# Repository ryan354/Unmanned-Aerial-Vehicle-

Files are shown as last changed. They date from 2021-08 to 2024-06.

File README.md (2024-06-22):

# Unmanned-Aerial-Vehicle-

Singapore Amazing Flying Machine Competition (SAFMC) is a Quadcopter or drone competition organized by DSO National Laboratories, Science Center Singapore and supported by the Ministry of Defense Singapore (MINDEF). In development of quadcopter many problems are found, such as collisions or crashes against obstacles and other quadcopter on the fly. This project discusses a PID control method for manipulating pitch and roll based on the proximity sensor as collision avoidance. The information obtained is then processed by PID control before entering the quadcopter flight controller. every quadcopter movement will be observed and evaluated to obtain stable movement. Use of wireless communication and telemetry data to facilitate the control of quadcopter with ground stations

okay let's dive into the project!!!!

1. UAV Design
<p align="center">
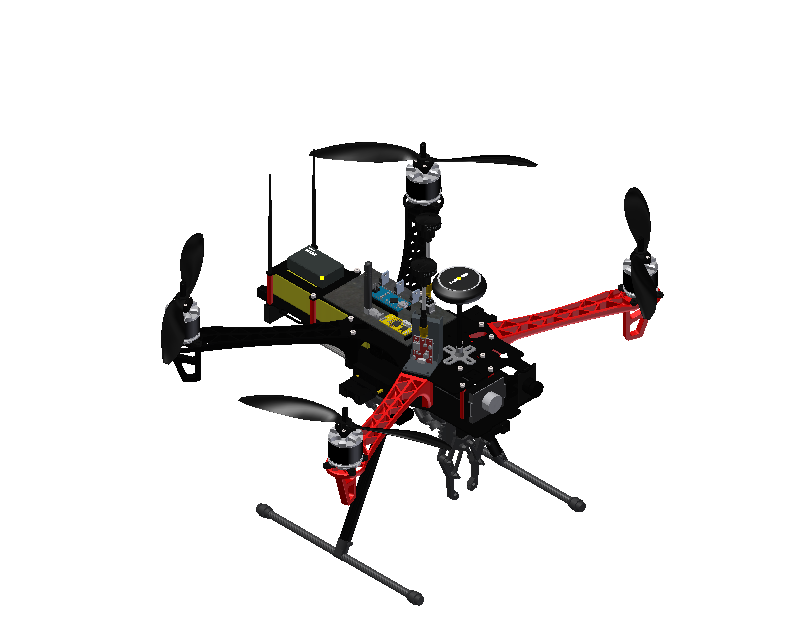
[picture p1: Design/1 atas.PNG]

</p>

<p align="center">
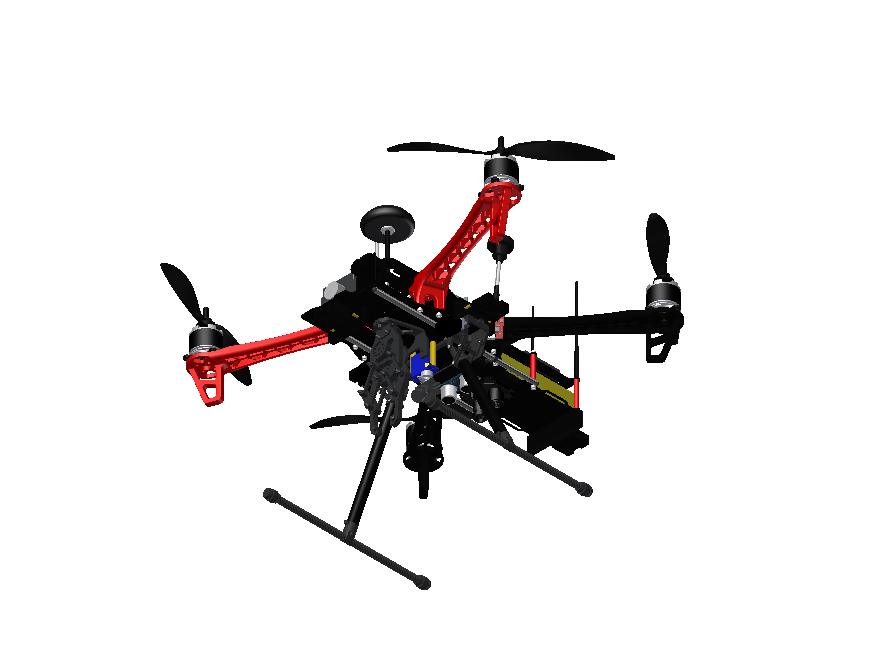
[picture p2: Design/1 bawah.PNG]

</p>

2. PCB (Printed Circuit Boards) Deisgn 
<p align="center">
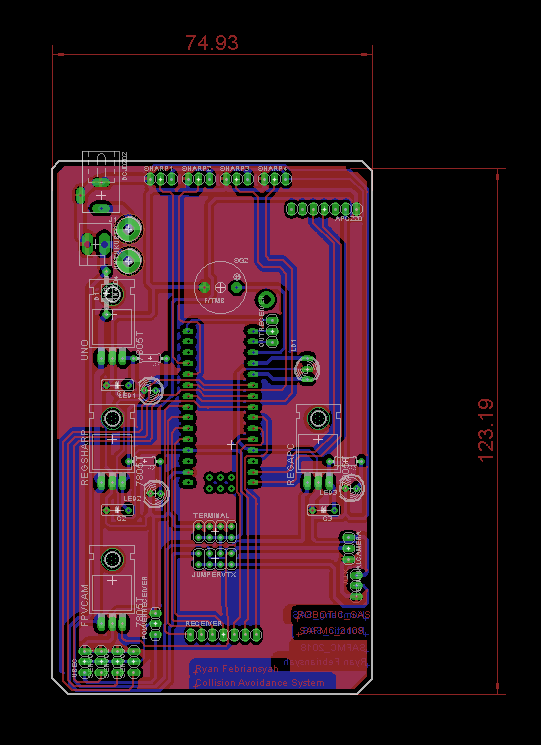
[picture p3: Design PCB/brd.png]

</p>

3. System Flowchart

<p align="center">
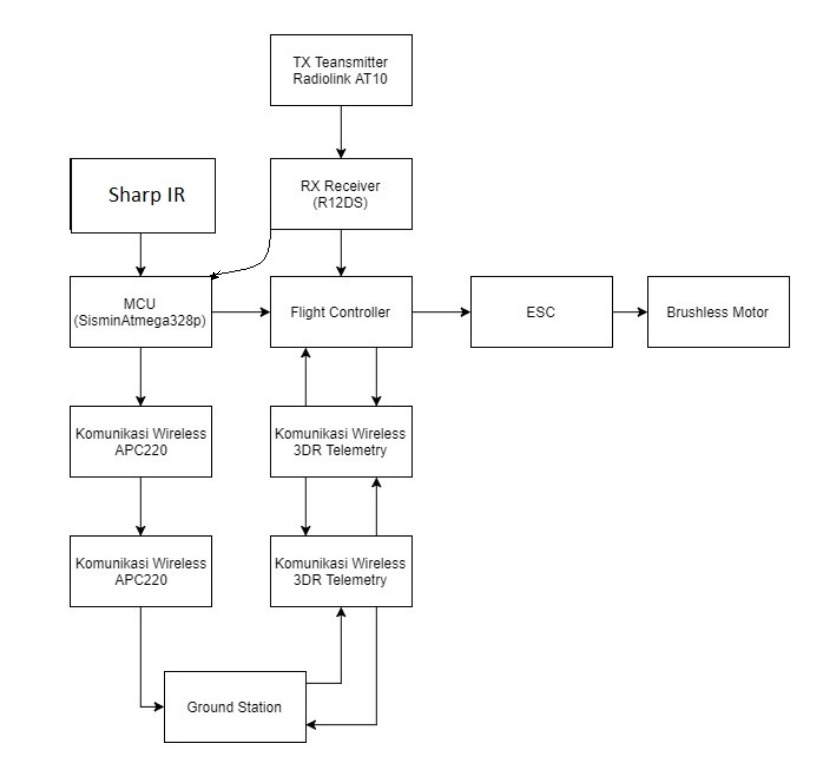
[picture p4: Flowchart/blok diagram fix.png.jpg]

</p>

Trial Video.
  
Unmanned-Aerial-Vehicle- (https://www.youtube.com/watch?v=qGmqiuEHwww)

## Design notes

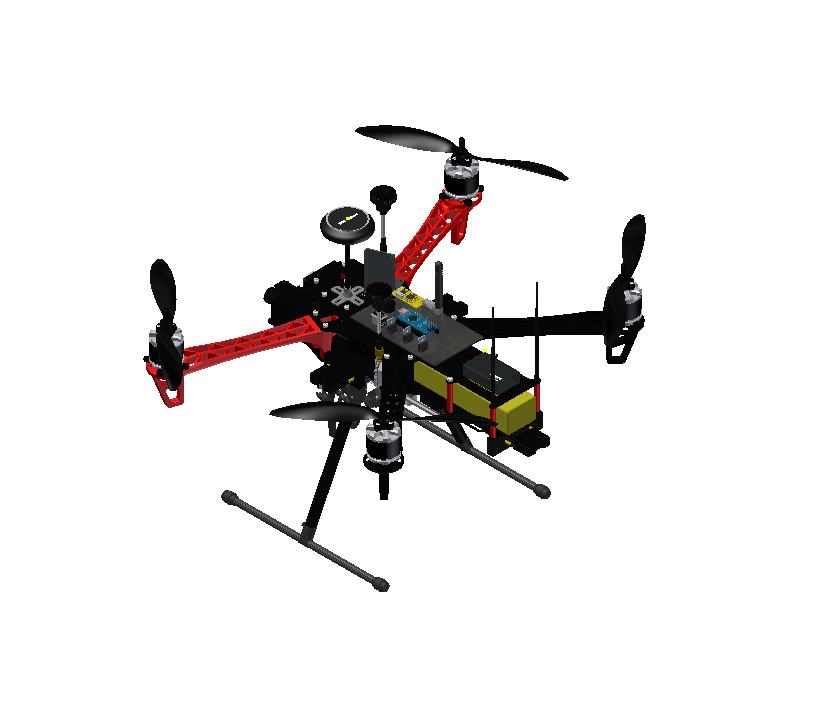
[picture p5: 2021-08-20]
Design/3 atas.PNG

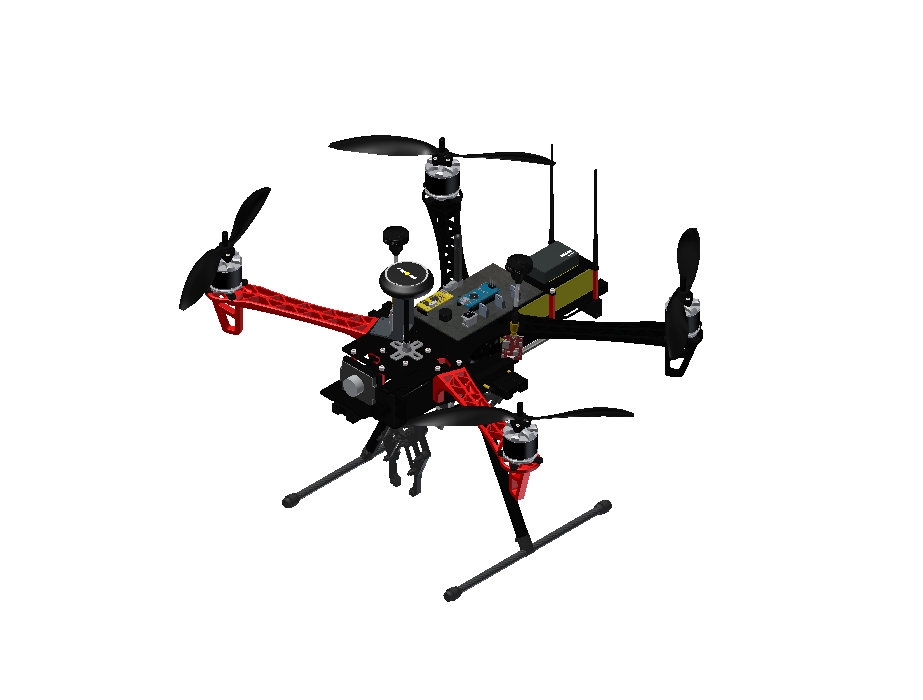
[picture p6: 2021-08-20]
Design/2 atas.PNG

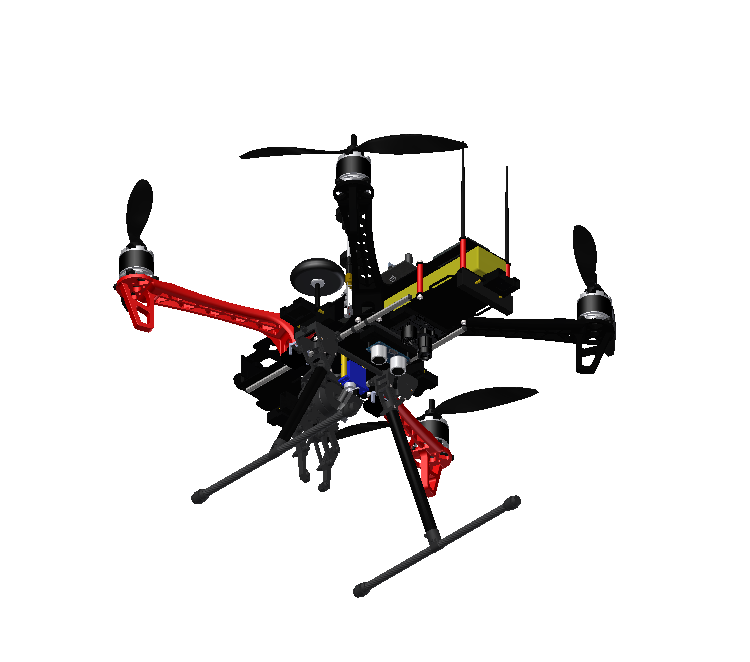
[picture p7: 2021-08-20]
Design/2 bawah.PNG

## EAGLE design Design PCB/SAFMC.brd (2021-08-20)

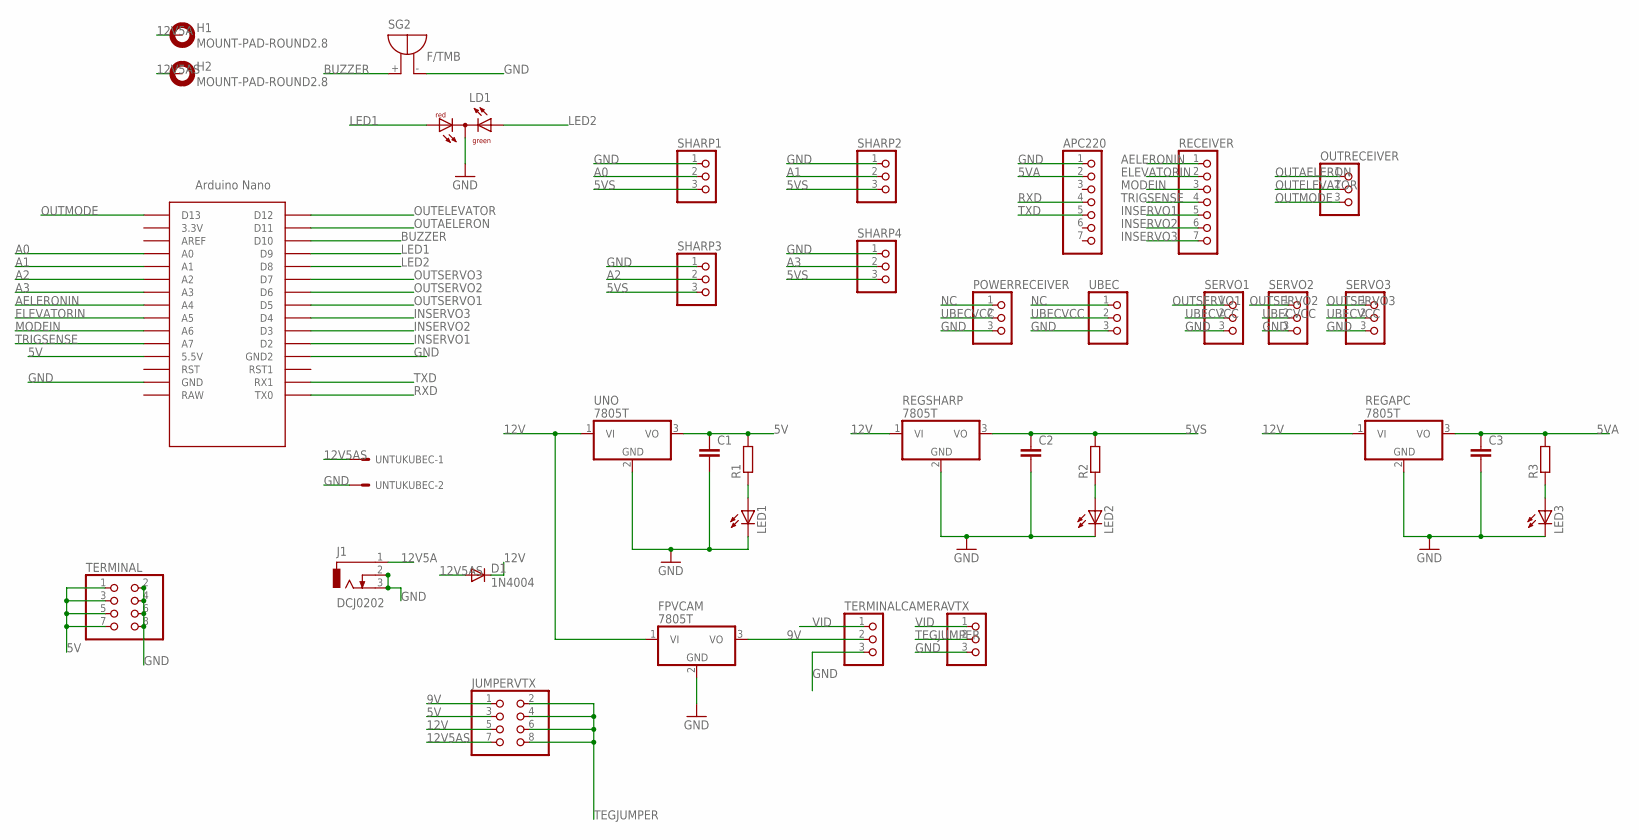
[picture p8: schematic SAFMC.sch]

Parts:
APC220: PINHD-1X7; 1X07
C1, C2, C3: C5/2.5; C5B2.5
D1: 1N4004; DO41-10
FPVCAM: 7805T; TO220H
H1, H2: MOUNT-PAD-ROUND2.8; 2,8-PAD
J1: DCJ0202
JUMPERVTX: PINHD-2X4; 2X04
LD1: DUOLED-RG-C; DUOLED-C-5MM
LED1, LED2, LED3: LED5MM
OUTRECEIVER: PINHD-1X3; 1X03
POWERRECEIVER: PINHD-1X3; 1X03
R1, R2, R3: R0204/7; 0204/7
RECEIVER: PINHD-1X7; 1X07
REGAPC: 7805T; TO220H
REGSHARP: 7805T; TO220H
SERVO1, SERVO2, SERVO3: PINHD-1X3; 1X03
SG2: F/TMB
SHARP1, SHARP2, SHARP3, SHARP4: PINHD-1X3; 1X03
TERMINAL: PINHD-2X4; 2X04
TERMINALCAMERA: PINHD-1X3; 1X03
U$2: NANO
UBEC: PINHD-1X3; 1X03
UNO: 7805T; TO220H
UNTUKUBEC: KK-156-2
VTX: PINHD-1X3; 1X03

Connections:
5V: C1.1, JUMPERVTX.3, R1.2, TERMINAL.1, TERMINAL.3, TERMINAL.5, TERMINAL.7, U$2.5V (5.5V), UNO.3 (VO)
5VA: APC220.2, C3.1, R3.2, REGAPC.3 (VO)
5VS: C2.1, R2.2, REGSHARP.3 (VO), SHARP1.3, SHARP2.3, SHARP3.3, SHARP4.3
9V: FPVCAM.3 (VO), JUMPERVTX.1, TERMINALCAMERA.2
12V: D1.C, FPVCAM.1 (VI), JUMPERVTX.5, REGAPC.1 (VI), REGSHARP.1 (VI), UNO.1 (VI)
12V5A: H1.B2,8, J1.1
12V5AS: D1.A, H2.B2,8, JUMPERVTX.7, UNTUKUBEC.1
A0: SHARP1.2, U$2.A0
A1: SHARP2.2, U$2.A1
A2: SHARP3.2, U$2.A2
A3: SHARP4.2, U$2.A3
AELERONIN: RECEIVER.1, U$2.A4
BUZZER: SG2.+, U$2.D10
ELEVATORIN: RECEIVER.2, U$2.A5
GND: APC220.1, C1.2, C2.2, C3.2, FPVCAM.2 (GND), J1.2, J1.3, LD1.C, LED1.K (C), LED2.K (C), LED3.K (C), POWERRECEIVER.3, REGAPC.2 (GND), REGSHARP.2 (GND), SERVO1.3, SERVO2.3, SERVO3.3, SG2.-, SHARP1.1, SHARP2.1, SHARP3.1, SHARP4.1, TERMINAL.2, TERMINAL.4, TERMINAL.6, TERMINAL.8, TERMINALCAMERA.3, U$2.GND, U$2.GND1 (GND2), UBEC.3, UNO.2 (GND), UNTUKUBEC.2, VTX.3
INSERVO1: RECEIVER.5, U$2.D2
INSERVO2: RECEIVER.6, U$2.D3
INSERVO3: RECEIVER.7, U$2.D4
LED1: LD1.AR, U$2.D9
LED2: LD1.AX (AG), U$2.D8
MODEIN: RECEIVER.3, U$2.A6
unnamed: LED3.A, R3.1
unnamed: LED1.A, R1.1
unnamed: LED2.A, R2.1
NC: POWERRECEIVER.1, UBEC.1
OUTAELERON: OUTRECEIVER.1, U$2.D11
OUTELEVATOR: OUTRECEIVER.2, U$2.D12
OUTMODE: OUTRECEIVER.3, U$2.D13
OUTSERVO1: SERVO1.1, U$2.D5
OUTSERVO2: SERVO2.1, U$2.D6
OUTSERVO3: SERVO3.1, U$2.D7
RXD: APC220.4, U$2.TX0
TEGJUMPER: JUMPERVTX.2, JUMPERVTX.4, JUMPERVTX.6, JUMPERVTX.8, VTX.2
TRIGSENSE: RECEIVER.4, U$2.A7
TXD: APC220.5, U$2.RX1
UBECVCC: POWERRECEIVER.2, SERVO1.2, SERVO2.2, SERVO3.2, UBEC.2
VID: TERMINALCAMERA.1, VTX.1

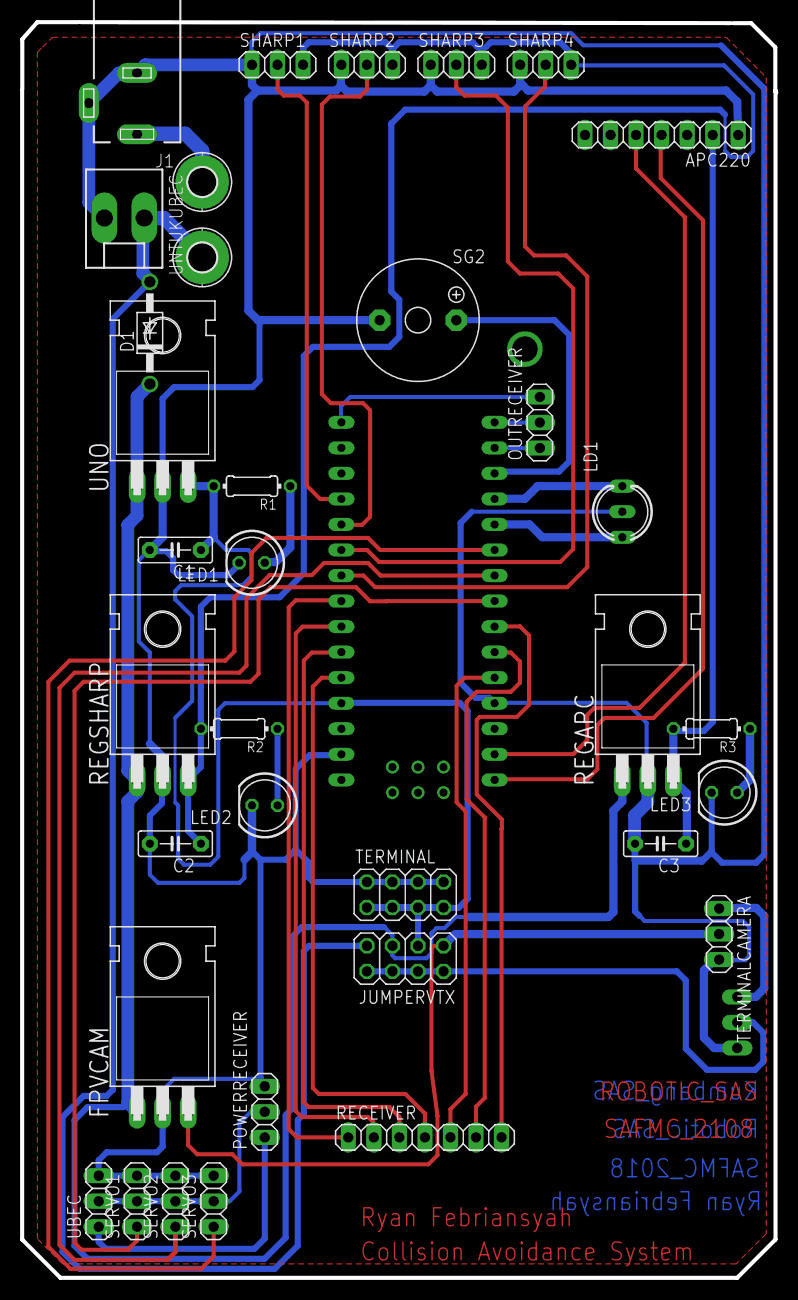
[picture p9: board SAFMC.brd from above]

Board: 2 copper layers, 75.0 x 124.9 mm, 37 parts (1 on the bottom side), 37 nets.

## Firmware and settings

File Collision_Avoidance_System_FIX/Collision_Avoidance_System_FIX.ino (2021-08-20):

#include <Servo.h>


//INPUT sensor sharp
int ir[4] = {A0, A1, A2, A3};
//INPUT Receiver
#define aeleronIN  A4
#define elevatorIN  A5
#define modeIN  2
#define triggerIN  3
#define inmode  9
//OUTPUT Receiver
#define aeleronOUT 11
#define elevatorOUT 12
#define modeOUT 13

//ServoINPUT
#define servofree 4
//ServoOUTPUT
#define outservocam 5
#define outservoarm 6
#define outservofree 7
//optional tambahan
#define lampu1 8
#define buzzer 10


int left, front, right, back;//nilai sensor
int temp = 0, temp1 = 0, temp2 = 0, temp3 = 0; //nilai Real
int e1, e2, e3, e4;//perbandingan nilai Real dengan Setpoint
int op1, op2, op3, op4, opx, opy;//nilai setelah ditambah KP
int x1 = 4;//pembagi===rata" dari 4 kali sampling data
int d1, d2, d3, d4;//nilai setelah dirata"

int centerValues = 1500;
int minValues = 1000;
int maxValues = 2000;
Servo myaeleron;
Servo myelevator;
Servo mymode;
Servo myservocam;
Servo myservoarm;
Servo myservofree;
unsigned int r_a ;
unsigned int r_af ;
unsigned int r_e ;
unsigned int r_ef ;
unsigned int r_m ;
unsigned int r_t  ;
unsigned int r_i;
unsigned int r_servo1;
unsigned int r_servo2;
unsigned int r_servo3;
int aeleronvalue = 0;
int elevatorvalue = 0;
int setpoint = 120;
int kp, ki, kd;
int valuer_a = 0;
int valuer_e = 0;

void setup() {
  Serial.begin(9600);
  //sensor pin function declare
  for (int i = 0 ; i < 4 ; i++) {
    pinMode(ir[i], INPUT);
  }
  //receiver pin function declare
  pinMode(aeleronIN, INPUT);
  pinMode(elevatorIN, INPUT);
  pinMode(modeIN, INPUT);
  pinMode(triggerIN, INPUT);
  pinMode(inmode, INPUT);

  //outreceiver pin functiondeclare
  pinMode(aeleronOUT, OUTPUT);
  pinMode(elevatorOUT, OUTPUT);
  pinMode(modeOUT, OUTPUT);
  digitalWrite(aeleronOUT, LOW);
  digitalWrite(elevatorOUT, LOW);
  digitalWrite(modeOUT, LOW);

  //servoin pin function declare
  pinMode(servofree, INPUT);

  //servoout pin function declare
  pinMode(outservocam, OUTPUT);
  pinMode(outservoarm, OUTPUT);
  pinMode(outservofree, OUTPUT);

  //optional pin function declare
  pinMode(buzzer, OUTPUT);
  pinMode(lampu1, OUTPUT);
  digitalWrite(buzzer, LOW);
  digitalWrite(lampu1, LOW);

  myaeleron.attach(aeleronOUT);
  myelevator.attach(elevatorOUT);
  mymode.attach(modeOUT);
  myservocam.attach(outservocam);
  myservoarm.attach(outservoarm);
  myservofree.attach(outservofree);

  int awalaeleron = map(centerValues, 1000, 2000, 0, 180);
  int awalelevator = map(centerValues, 1000, 2000, 0, 180);
  int awalmode = map(minValues, 1000, 2000, 0, 180);
  myaeleron.write(awalaeleron);
  myelevator.write(awalelevator);
  mymode.write(awalmode);
  int awalservocam = 60;
  int awalservoarm = 60;
  int awalservofree = 60;
  myservofree.write(awalservofree);


}

void loop() {
  bacareceiver();
  bacasensor();
  mode();
  calculate();
  controllampu();
  kirimdata();
}

void bacasensor() {
  setpoint = map(setpoint, 20, 150, 0, 1023);
  temp = 0;
  temp1 = 0;
  temp2 = 0;
  temp3 = 0;
  for (int i = 0; i <= x1; i++)
  {
    left = analogRead(ir[0]);
    delay(2);
    temp = temp + left;
  }
  d1 = temp / x1;
  for (int i = 0; i <= x1; i++)
  {
    right = analogRead(ir[1]);
    delay(2);
    temp1 = temp1 + right;
  }
  d3 = temp1 / x1;
  for (int i = 0; i <= x1; i++)
  {
    front = analogRead(ir[2]);
    delay(2);
    temp2 = temp2 + front;
  }
  d2 = temp2 / x1;
  for (int i = 0; i <= x1; i++)
  {
    back = analogRead(ir[3]);
    delay(2);
    temp3 = temp3 + back;
  }
  d4 = temp3 / x1;
  /*
    Serial.println(d1);
    Serial.print(",");
    Serial.print(d2);
    Serial.print(",");
    Serial.print(d3);
    Serial.print(",");
    Serial.println(d4);
  */

}

void bacareceiver() {


  r_a = pulseIn(aeleronIN, HIGH, 24000);
  r_e = pulseIn(elevatorIN, HIGH, 24000);
  r_m = pulseIn(modeIN, HIGH, 24000);
  r_t = pulseIn(triggerIN, HIGH, 24000);
  r_i = pulseIn(inmode, HIGH, 24000);

  int i;
  int numReadings = 10;

  // Take an average of all the readings.
  for (i = 0; i < numReadings; i++) {

    valuer_a = valuer_a + r_a;

    delay(1);
  }

  valuer_a = valuer_a / numReadings;

  for (i = 0; i < numReadings; i++) {

    valuer_e = valuer_e + r_e;
    delay(1);
  }

  //Take an average of all the readings.
  valuer_e = valuer_e / numReadings;

  /*
    Serial.print(r_a);
    Serial.print(",");
    Serial.println(r_e);
    Serial.print(",");
    Serial.println(r_m);
    Serial.print(",");
    Serial.print(r_t);
    Serial.print(",");
    Serial.println(r_i);
  */

}

void calculate() {

  e1 = d1 - setpoint;
  e2 = d2 - setpoint;
  e3 = d3 - setpoint;
  e4 = d4 - setpoint;


  op1 = e1 * kp;
  op2 = e2 * kp;
  op3 = e3 * kp;
  op4 = e4 * kp;

  int f1 = op1 * 0.5;
  int f2 = op2 * 0.5;
  int f3 = op3 * 0.5;
  int f4 = op4 * 0.5;

  aeleronvalue = r_a - f3 + f1;
  elevatorvalue = r_e - f4 + f2;
  int aeleronToFc = map(aeleronvalue , minValues, maxValues, 0, 179);
  int elevatorToFc = map(elevatorvalue , minValues, maxValues, 0, 179);

  //cari nilai tengah aeleron&elevator to fc


  //  if (1400 < aeleronvalue < 1500) {
  //    myaeleron.write(90);
  //  }
  //  if (aeleronvalue > 1500) {
  //    myaeleron.write(aeleronToFc);
  //  }
  //  if (aeleronvalue < 1400) {
  //    myaeleron.write(aeleronToFc);
  //  }
  //
  //
  //  if (1400 < elevatorvalue < 1500) {
  //    myelevator.write(90);
  //  }
  //  if (elevatorvalue > 1500) {
  //    myelevator.write(elevatorToFc);
  //  }
  //  if (elevatorvalue < 1400) {
  //    myelevator.write(elevatorToFc);
  //  }



  myaeleron.write(aeleronToFc);
  myelevator.write(elevatorToFc);
  //Serial.print(aeleronvalue);
  //Serial.print(",");
  //Serial.println(elevatorvalue);

}



void mode() {

  int sensparam = 180;//nilai sensor setpoint


  //mode with collision avoidance
  if (1300 < r_i <= 1600 ) {
    digitalWrite(buzzer, LOW);
    int readmode = map(r_m, minValues, maxValues, 0, 180);
    mymode.write(readmode);
    kp = 1;
    ki = 1;
    kd = 1;

    if (d1 > sensparam) {
      digitalWrite(buzzer, HIGH);
    }
    if (d2 > sensparam) {
      digitalWrite(buzzer, HIGH);

    }

    if (d3 > sensparam) {
      digitalWrite(buzzer, HIGH);


    }
    if (d4 > sensparam)
    {
      digitalWrite(buzzer, HIGH);

    }

    if (d1 > sensparam && d2 > sensparam) {
      digitalWrite(buzzer, HIGH);

    }
    if (d1 > sensparam && d3 > sensparam) {
      digitalWrite(buzzer, HIGH);


    }
    if (d1 > sensparam && d3 > sensparam) {
      digitalWrite(buzzer, HIGH);


    }
    if (d1 > sensparam && d4 > sensparam) {
      digitalWrite(buzzer, HIGH);


    }
    if (d2 > sensparam && d3 > sensparam) {
      digitalWrite(buzzer, HIGH);

    }
    if (d2 > sensparam && d4 > sensparam) {
      digitalWrite(buzzer, HIGH);

    }
    if (d3 > sensparam && d4 > sensparam) {
      digitalWrite(buzzer, HIGH);

    }
    if (d1 > sensparam && d2 > sensparam && d3 > sensparam ) {
      digitalWrite(buzzer, HIGH);

    }

    if (d2 > sensparam && d3 > sensparam && d4 > sensparam ) {

      digitalWrite(buzzer, HIGH);


    }

    if (d1 > sensparam && d3 > sensparam && d4 > sensparam ) {
      digitalWrite(buzzer, HIGH);


    }
    if (d1 > sensparam && d2 > sensparam && d4 > sensparam ) {
      digitalWrite(buzzer, HIGH);

    }

  }

  if ( r_i >  1600) {
    digitalWrite(buzzer, LOW);
    int readmode = map(r_m, minValues, maxValues, 0, 180);
    mymode.write(readmode);
    kp = 0;
    ki = 0;
    kd = 0;

    if (d1 > sensparam) {
      digitalWrite(buzzer, HIGH);
      landingmode();

    }
    if (d2 > sensparam) {
      digitalWrite(buzzer, HIGH);
      landingmode();

    }

    if (d3 > sensparam) {
      digitalWrite(buzzer, HIGH);
      landingmode();


    }
    if (d4 > sensparam)
    {
      digitalWrite(buzzer, HIGH);
      landingmode();

    }

    if (d1 > sensparam && d2 > sensparam) {
      digitalWrite(buzzer, HIGH);

      landingmode();
    }
    if (d1 > sensparam && d3 > sensparam) {
      digitalWrite(buzzer, HIGH);
      landingmode();

    }
    if (d1 > sensparam && d3 > sensparam) {
      digitalWrite(buzzer, HIGH);

      landingmode();

    }
    if (d1 > sensparam && d4 > sensparam) {
      digitalWrite(buzzer, HIGH);

      landingmode();

    }
    if (d2 > sensparam && d3 > sensparam) {
      digitalWrite(buzzer, HIGH);

      landingmode();
    }
    if (d2 > sensparam && d4 > sensparam) {
      digitalWrite(buzzer, HIGH);
      landingmode();

    }
    if (d3 > sensparam && d4 > sensparam) {
      digitalWrite(buzzer, HIGH);

      landingmode();
    }
    if (d1 > sensparam && d2 > sensparam && d3 > sensparam ) {
      digitalWrite(buzzer, HIGH);

      landingmode();
    }

    if (d2 > sensparam && d3 > sensparam && d4 > sensparam ) {
      digitalWrite(buzzer, HIGH);


      landingmode();


    }

    if (d1 > sensparam && d3 > sensparam && d4 > sensparam ) {
      digitalWrite(buzzer, HIGH);


      landingmode();

    }
    if (d1 > sensparam && d2 > sensparam && d4 > sensparam ) {
      digitalWrite(buzzer, HIGH);


      landingmode();

    }

  }
  if (r_i <= 1300) {
    digitalWrite(buzzer, LOW);
    int readmode = map(r_m, minValues, maxValues, 0, 180);
    mymode.write(readmode);
    kp = 0;
    ki = 0;
    kd = 0;


  }




}


void landingmode() {

  mymode.write(125);

}







void kirimdata() {
  Serial.print(r_a);
  Serial.print(",");
  Serial.print(r_e);
  Serial.print(",");
  Serial.print(r_m);
  Serial.print(",");
  Serial.print(r_t);
  Serial.print(",");
  Serial.print(r_i);
  Serial.print(",");
  Serial.print(d1);
  Serial.print(",");
  Serial.print(d2);
  Serial.print(",");
  Serial.print(d3);
  Serial.print(",");
  Serial.print(d4);
  Serial.print(",");
  Serial.print(aeleronvalue);
  Serial.print(",");
  Serial.println(elevatorvalue);


}



void controllampu() {
  if (r_t <= 1400) {
    digitalWrite(lampu1, HIGH);
  }
  else {
    digitalWrite(lampu1, LOW);
  }


}
